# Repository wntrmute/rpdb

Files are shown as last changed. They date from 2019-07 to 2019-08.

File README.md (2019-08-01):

# Robot Power Distribution Board

This is a simple power distribution board that offers direct output to a motor controller, stable 5V and 3.3V rails, and an I2C expander.

## Version history

* [4.0](v4/) - added power and motor LEDs with SMD resistors
* [3.0](v3/) - updated silkscreen to improve capacitor placement
* [2.0](v2/) - first working prototype.

## Specifications

* Input voltage: 6-12V
* Max current: 1.2A draw through the 5V and 800 mA through the 3.3V rails

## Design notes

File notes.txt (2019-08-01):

+ would the pwr kill switch be better placed after the vregs? this avoids
  the cap drain time (which is currently somewhere on the order of 5s)
+ should the power switches be considered emergency kill switches? they don't
  have a high enough current rating, so I don't think so.
+ the traces should be a lot wider, maybe 25mm

Power limits
+==================+=========+=========+
| Part             | Voltage | Current |
+==================+=========+=========+
| L7805            | 35      | 1.2A    |
| LD1117V33        | 15      | 800mA   |
| 1000uF cap       | 25      |         |
| 100uF cap        | 25      |         |
| 2x8 header       |         | 3A      |
+------------------+---------+---------+

some reading:
+ https://www.electronicdesign.com/power/motor-driver-pcb-layout-guidelines-part-1

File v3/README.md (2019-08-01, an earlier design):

# Robot Power Distribution Board v3

For this revision, I fixed the cap silkscreens, which necessitated
shifting some things around.

## Specifications

* Dimensions: 77.2 x 31.8 mm (3.04 x 1.25 inches).
* Input voltage: 6-12V
* Output voltages: 3.3V @ 800mA, 5V @ 1.5A

## Bill of materials

* 1x RPDBv3 PCB ([OSHPark](https://oshpark.com/shared_projects/M7HbM4bz))
* 2x 5mm pitch screw terminal ([Sparkfun](https://www.sparkfun.com/products/8432))
* 2x mini power switch([Sparkfun](https://www.sparkfun.com/products/102))
* 1x 1000uF electrolytic capacitor ([Sparkfun](https://www.sparkfun.com/products/8982))
* 2x 100uF electrolytic capacitor ([Sparkfun](https://www.sparkfun.com/products/96))
* 1x L7805 5V voltage regulator ([Sparkfun](https://www.sparkfun.com/products/107))
* 3x 2x8 header ([Sparkfun](https://www.sparkfun.com/products/13156))

## Assembly

1. Solder the 2x8 headers.
2. Solder the voltage regulators. Screw them in if desired.
3. Solder in the switches.
4. Solder in the terminals.
5. Solder in the 100uF capacitors.
6. Solder in the 1000uF capacitor.

## Usage

* Wire the battery into the power terminal.
* Wire the motor controller to the motor terminal.
* Connect up parts to the appropriate rail.
* Note that toggling the kill switches under high motor load can cause
  them to fuse.

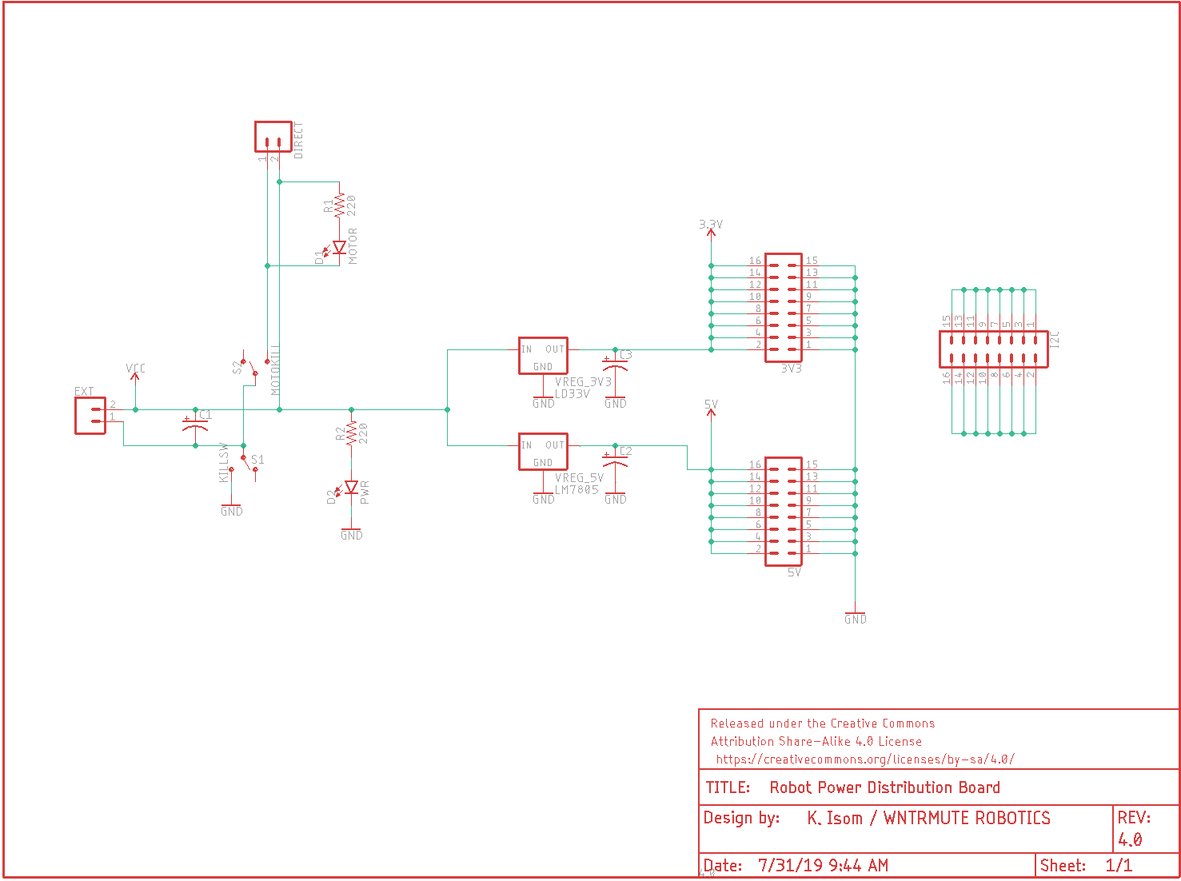
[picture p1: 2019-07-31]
v4/pdb_v4.png

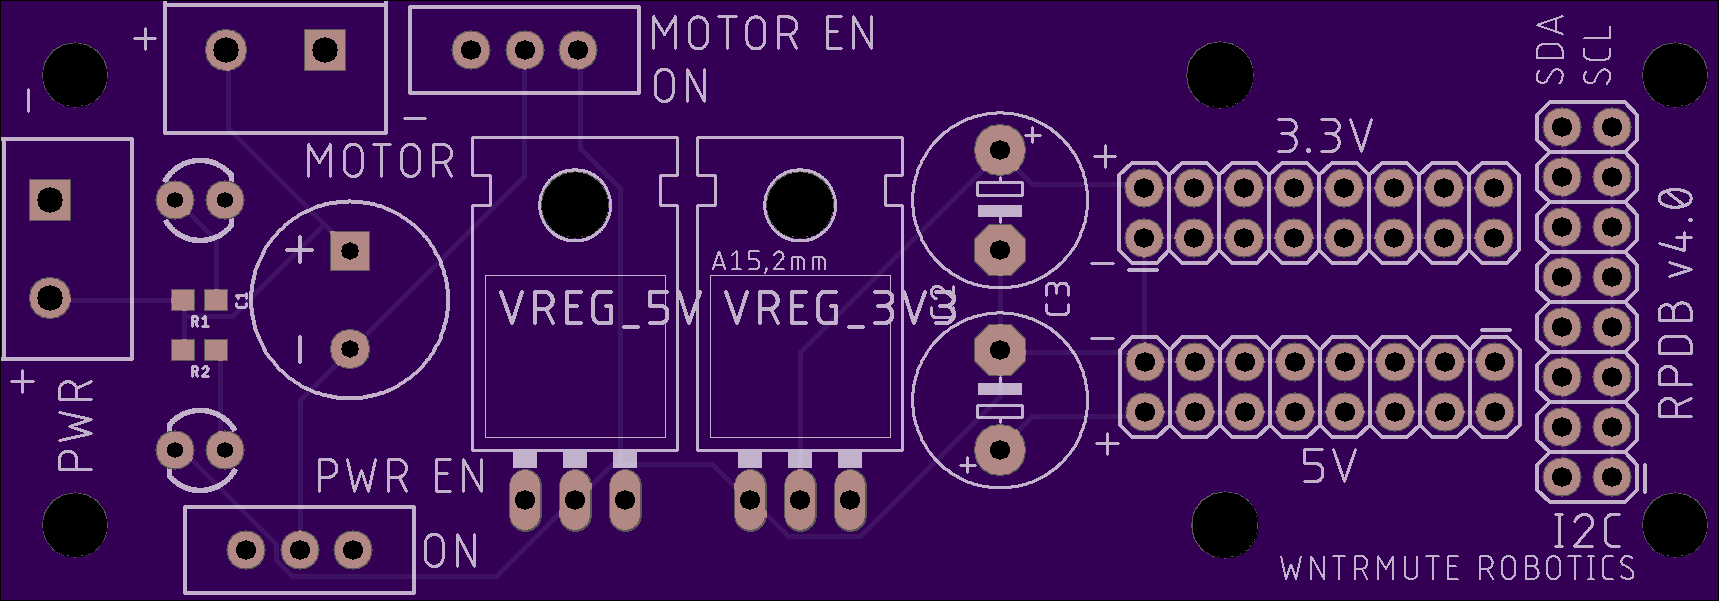
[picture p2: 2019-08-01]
v4/pdb_v4_board_top.png

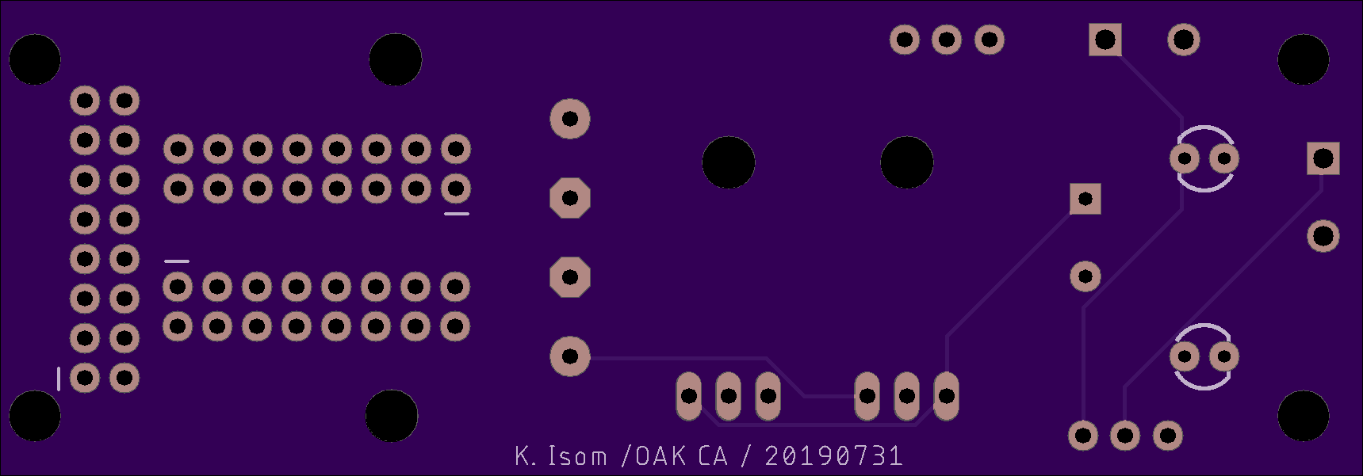
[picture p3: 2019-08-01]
v4/pdb_v4_board_bottom.png

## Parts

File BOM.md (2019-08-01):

## Bill of materials

* 1x RPDBv3 PCB ([OSHPark](https://oshpark.com/shared_projects/M7HbM4bz))
* 2x 5mm pitch screw terminal ([Sparkfun](https://www.sparkfun.com/products/8432))
* 2x mini power switch([Sparkfun](https://www.sparkfun.com/products/102))
* 1x 1000uF electrolytic capacitor ([Sparkfun](https://www.sparkfun.com/products/8982), [DigiKey](https://www.digikey.com/product-detail/en/nichicon/UVZ1E102MPD/493-1305-ND/589046))
* 2x 100uF electrolytic capacitor ([Sparkfun](https://www.sparkfun.com/products/96), [DigiKey](https://www.digikey.com/products/en?keywords=P10269-ND))
* 1x L7805 5V voltage regulator ([Sparkfun](https://www.sparkfun.com/products/107), [DigiKey](https://www.digikey.com/product-detail/en/stmicroelectronics/L7805ABV/497-2947-5-ND/634711))
* 1x LD333V 3.3V voltage regulator ([Sparkfun](https://www.sparkfun.com/products/526), [DigiKey](https://www.digikey.com/product-detail/en/stmicroelectronics/LD1117V33C/497-1492-5-ND/586013))
* 3x 2x8 header ([Sparkfun](https://www.sparkfun.com/products/13156))

### For v4

* 2x 3mm LED ([Sparkfun](https://www.sparkfun.com/products/9650))
* 2x 0603 220 resistor ([Digikey](https://www.digikey.com/product-detail/en/te-connectivity-passive-product/CRGP0603F220R/A130408CT-ND/8578240))

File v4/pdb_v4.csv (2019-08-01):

Qty | Value | Device | Package | Parts | Description | DESIGNER | PROD_ID | REV | SF_ID | SF_SKU | SPICEPREFIX | VALUE | VERSION
2 |  | CONN_025MM | SCREWTERMINAL-5MM-2 | DIRECT, EXT | Multi connection point. Often used as Generic Header-pin footprint for 0.1 inch spaced/style header connections |  |  |  |  | PRT-08432
3 |  | CONN_08X2_HEADER | 2X8 | 3V3, 5V, I2C | Multi connection point. Often used as Generic Header-pin footprint for 0.1 inch spaced/style header connections
1 | 1000uF | 1000UF-RADIAL-5MM-25V-20% | CPOL-RADIAL-5MM-10MM | C1 | 1,000µF/1mF ceramic capacitors |  | CAP-09538 |  |  |  |  | 1mF
2 | 100uF | CPOL-USE5-8.5 | E5-8,5 | C2, C3 | POLARIZED CAPACITOR, American symbol |  |  |  |  |  | C
2 | 220 | 220OHM-0603-1/10W-1% | 0603 | R1, R2 | 220Ω resistor |  | RES-07861 |  |  |  |  | 220
1 | FRAME-LETTERNO_PACKAGE | FRAME-LETTERNO_PACKAGE | DUMMY | FRAME1 | Schematic Frame - Letter | K. Isom / WNTRMUTE ROBOTICS |  | 4.0 |  |  |  |  | 4.0
1 | KILLSW | SWITCH-SPDT-PTH-11.6X4.0MM-LOCK | SWITCH_SPDT_PTH_11.6X4.0MM_LOCK | S1 | Single Pole, Double Throw (SPDT) Switch |  | SWCH-08261 |  |  | COM-00102
1 | LD33V | V_REG_LD1117VXX | 78XXL | VREG_3V3 | LD1117VXX voltage regulator. We carry the 3.3V version (COM-00526) in TO-220 package.
1 | LM7805 | V_REG_78XX-TO-220 | TO-220-ALT | VREG_5V | Voltage Regulator |  | VREG-08450 |  | COM-00107
1 | MOTOKILL | SWITCH-SPDT-PTH-11.6X4.0MM-LOCK | SWITCH_SPDT_PTH_11.6X4.0MM_LOCK | S2 | Single Pole, Double Throw (SPDT) Switch |  | SWCH-08261 |  |  | COM-00102
1 | MOTOR | LED3MM | LED_3MM | D1 | LED (Generic) |  | DIO-08794
1 | PWR | LED3MM | LED_3MM | D2 | LED (Generic) |  | DIO-08794

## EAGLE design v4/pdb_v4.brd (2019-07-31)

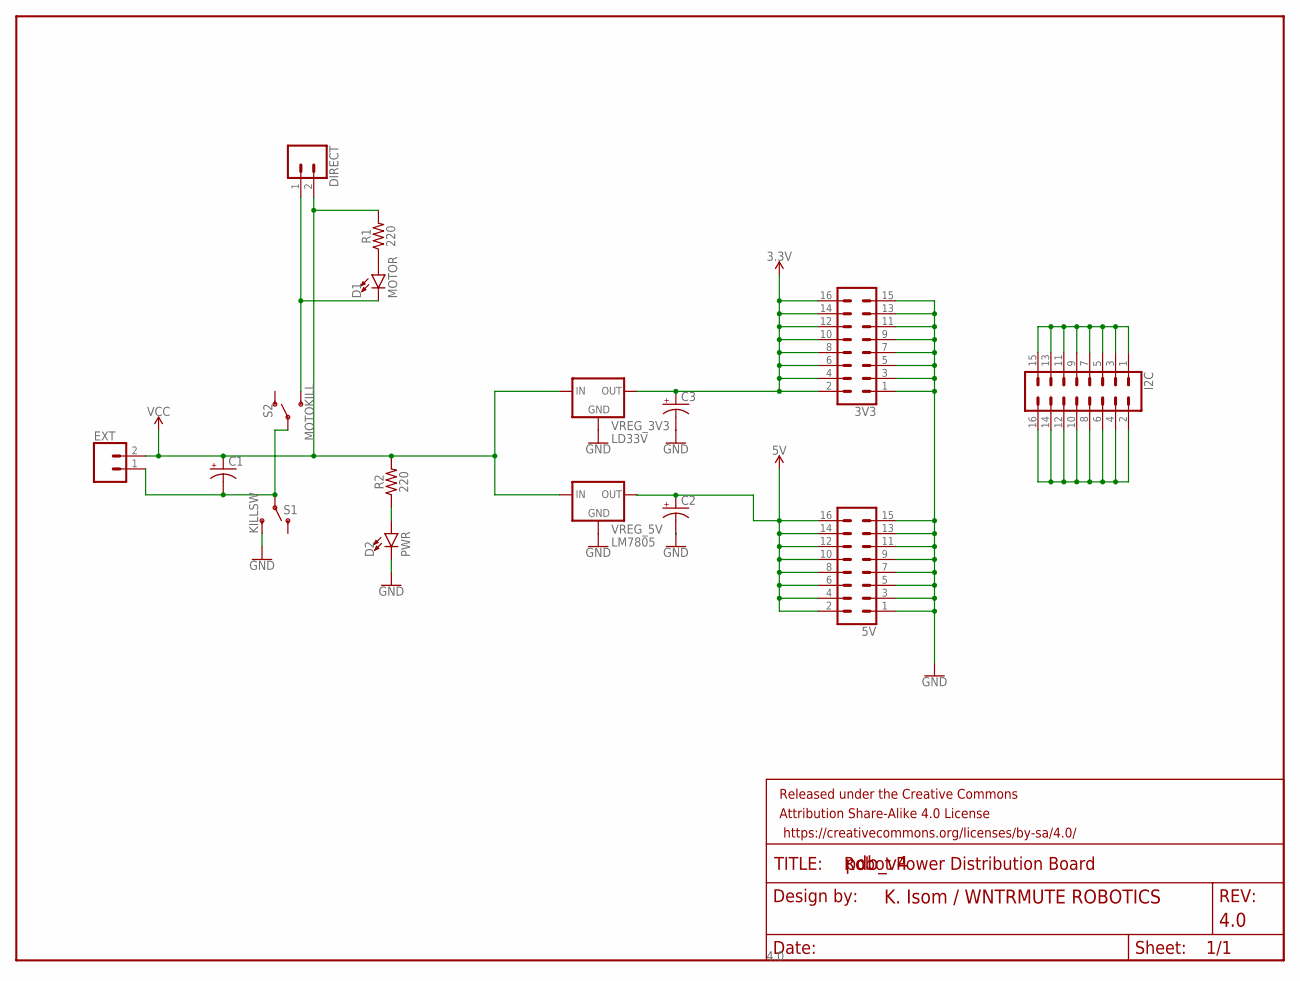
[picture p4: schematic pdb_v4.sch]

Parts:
3V3, 5V: CONN_08X2_HEADER; 2X8
C1: 1000uF; CPOL-RADIAL-5MM-10MM
C2, C3: 100uF; E5-8,5
D1: MOTOR; LED_3MM
D2: PWR; LED_3MM
DIRECT: CONN_025MM; SCREWTERMINAL-5MM-2
EXT: CONN_025MM; SCREWTERMINAL-5MM-2
FRAME1: FRAME-LETTERNO_PACKAGE; DUMMY
I2C: CONN_08X2_HEADER; 2X8
R1, R2: 220; 0603
S1: KILLSW; SWITCH_SPDT_PTH_11.6X4.0MM_LOCK
S2: MOTOKILL; SWITCH_SPDT_PTH_11.6X4.0MM_LOCK
VREG_3V3: LD33V; 78XXL
VREG_5V: LM7805; TO-220-ALT

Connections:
3.3V: 3V3.2, 3V3.4, 3V3.6, 3V3.8, 3V3.10, 3V3.12, 3V3.14, 3V3.16, C3.+, VREG_3V3.GND (OUT)
5V: 5V.2, 5V.4, 5V.6, 5V.8, 5V.10, 5V.12, 5V.14, 5V.16, C2.+, VREG_5V.OUT
GND: 3V3.1, 3V3.3, 3V3.5, 3V3.7, 3V3.9, 3V3.11, 3V3.13, 3V3.15, 5V.1, 5V.3, 5V.5, 5V.7, 5V.9, 5V.11, 5V.13, 5V.15, C2.-, C3.-, D2.K (C), S1.3 (S), VREG_3V3.IN (GND), VREG_5V.GND
unnamed: C1.-, EXT.1, S1.2, S2.2
unnamed: D1.A, R1.1
unnamed: D2.A, R2.1
unnamed: I2C.1, I2C.3, I2C.5, I2C.7, I2C.9, I2C.11, I2C.13, I2C.15
unnamed: I2C.2, I2C.4, I2C.6, I2C.8, I2C.10, I2C.12, I2C.14, I2C.16
unnamed: D1.K (C), DIRECT.1, S2.3 (S)
VCC: C1.+, DIRECT.2, EXT.2, R1.2, R2.2, VREG_3V3.OUT (IN), VREG_5V.IN

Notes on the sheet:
Robot Power Distribution Board

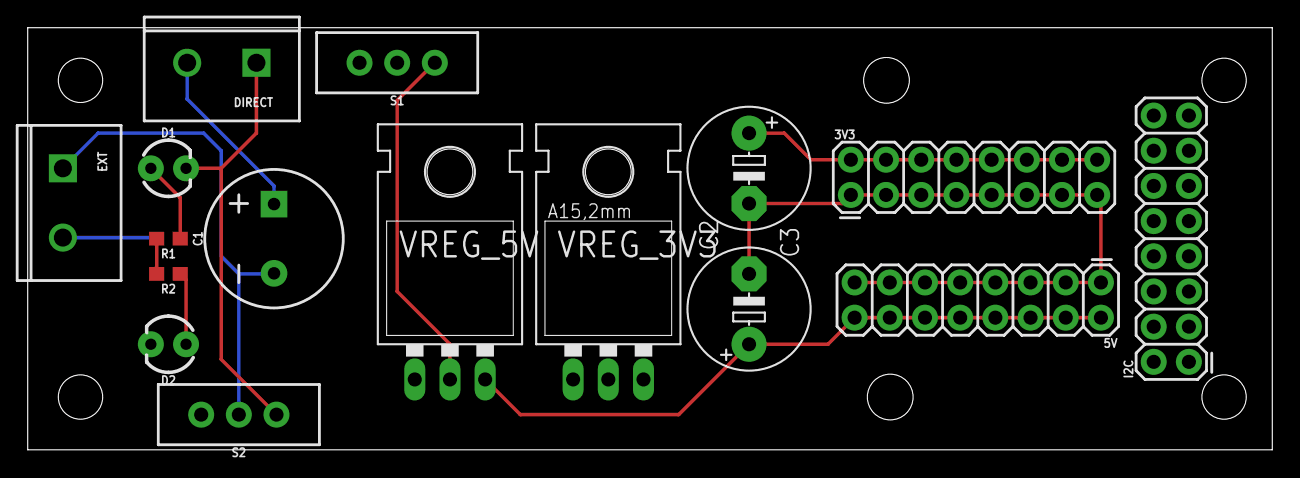
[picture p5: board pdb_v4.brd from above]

Board: 2 copper layers, 89.8 x 30.5 mm, 17 parts (0 on the bottom side), 10 nets.

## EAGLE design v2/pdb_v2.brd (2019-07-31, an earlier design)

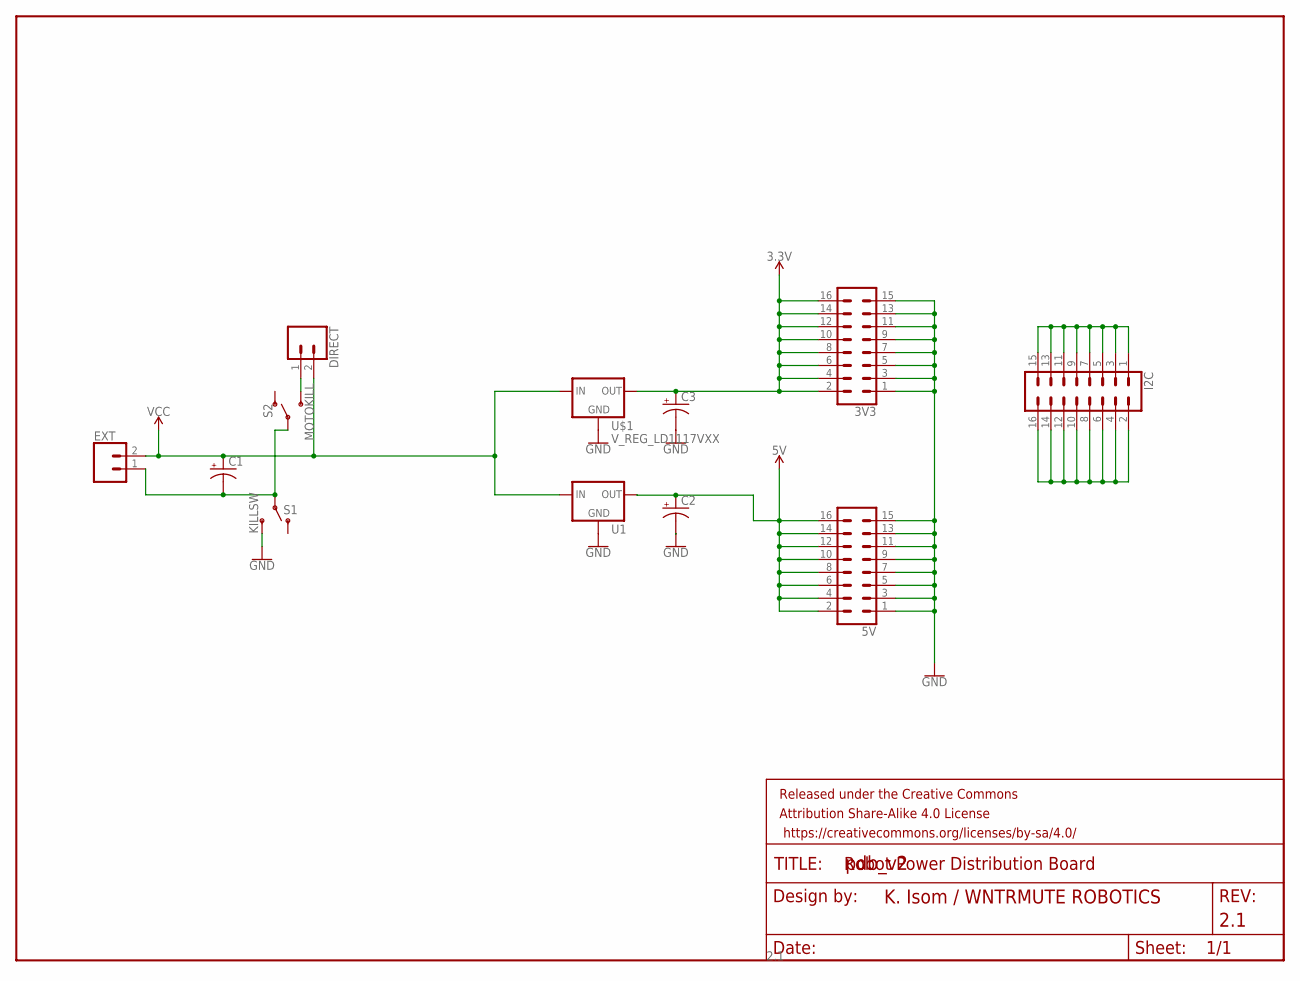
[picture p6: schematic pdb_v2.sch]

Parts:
3V3, 5V: CONN_08X2_HEADER; 2X8
C1: 1000µF; E5-10,5
C2, C3: 100uF; E5-8,5
DIRECT: CONN_025MM; SCREWTERMINAL-5MM-2
EXT: CONN_025MM; SCREWTERMINAL-5MM-2
FRAME1: FRAME-LETTERNO_PACKAGE; DUMMY
I2C: CONN_08X2_HEADER; 2X8
S1: KILLSW; SWITCH_SPDT_PTH_11.6X4.0MM_LOCK
S2: MOTOKILL; SWITCH_SPDT_PTH_11.6X4.0MM_LOCK
U1: V_REG_78XX-TO-220; TO-220-ALT
U$1: V_REG_LD1117VXX; 78XXL

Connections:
3.3V: 3V3.2, 3V3.4, 3V3.6, 3V3.8, 3V3.10, 3V3.12, 3V3.14, 3V3.16, C3.+, U$1.GND (OUT)
5V: 5V.2, 5V.4, 5V.6, 5V.8, 5V.10, 5V.12, 5V.14, 5V.16, C2.+, U1.OUT
GND: 3V3.1, 3V3.3, 3V3.5, 3V3.7, 3V3.9, 3V3.11, 3V3.13, 3V3.15, 5V.1, 5V.3, 5V.5, 5V.7, 5V.9, 5V.11, 5V.13, 5V.15, C2.-, C3.-, S1.3 (S), U1.GND, U$1.IN (GND)
unnamed: C1.-, EXT.1, S1.2, S2.2
unnamed: I2C.1, I2C.3, I2C.5, I2C.7, I2C.9, I2C.11, I2C.13, I2C.15
unnamed: I2C.2, I2C.4, I2C.6, I2C.8, I2C.10, I2C.12, I2C.14, I2C.16
unnamed: DIRECT.1, S2.3 (S)
VCC: C1.+, DIRECT.2, EXT.2, U1.IN, U$1.OUT (IN)

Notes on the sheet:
Robot Power Distribution Board

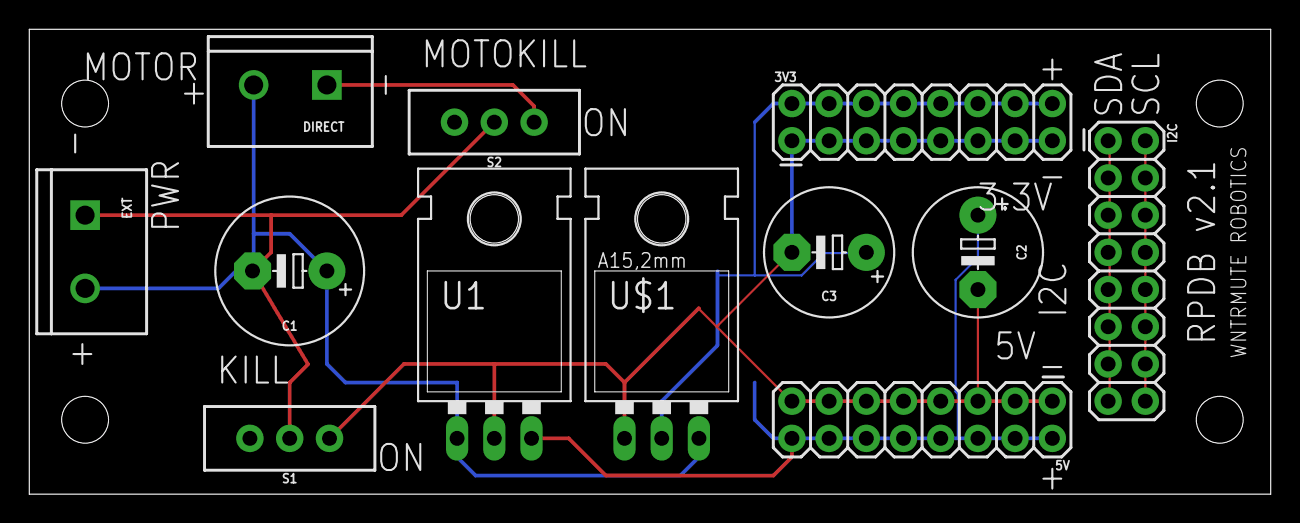
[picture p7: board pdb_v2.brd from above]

Board: 2 copper layers, 84.8 x 31.7 mm, 13 parts (0 on the bottom side), 8 nets.

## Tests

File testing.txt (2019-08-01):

Test plan
=========

Input voltage: 8V

1. Set up 8Ω load resistor on motor controller to test 1A through
   terminal.
2. Set up a 2x1Ω load resistor network in series with a 4Ω load resistor
   on the 3.3V rail to supply 733mA, close to 800mA rating.
3. Move this resistor setup to the 5V rail to test with 1.15A, close to
   1.1A rating.

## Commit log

2019-07-31 Initial import of boards.
    [pdb_v2.brd, pdb_v2.csv, pdb_v2.sch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]
2019-07-31 Add README.
    Start documenting the board.
2019-07-31 Reorg and cleanup
    [pdb_v2.brd, pdb_v2.csv, pdb_v2.sch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]
2019-08-01 Clean up BOM CSVs.
    [pdb_v2.csv, pdb_v3.csv, pdb_v4.csv]

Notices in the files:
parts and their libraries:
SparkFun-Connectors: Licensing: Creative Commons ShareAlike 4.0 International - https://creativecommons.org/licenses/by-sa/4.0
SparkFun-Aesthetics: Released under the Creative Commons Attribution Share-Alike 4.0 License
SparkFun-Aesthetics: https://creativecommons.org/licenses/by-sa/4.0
